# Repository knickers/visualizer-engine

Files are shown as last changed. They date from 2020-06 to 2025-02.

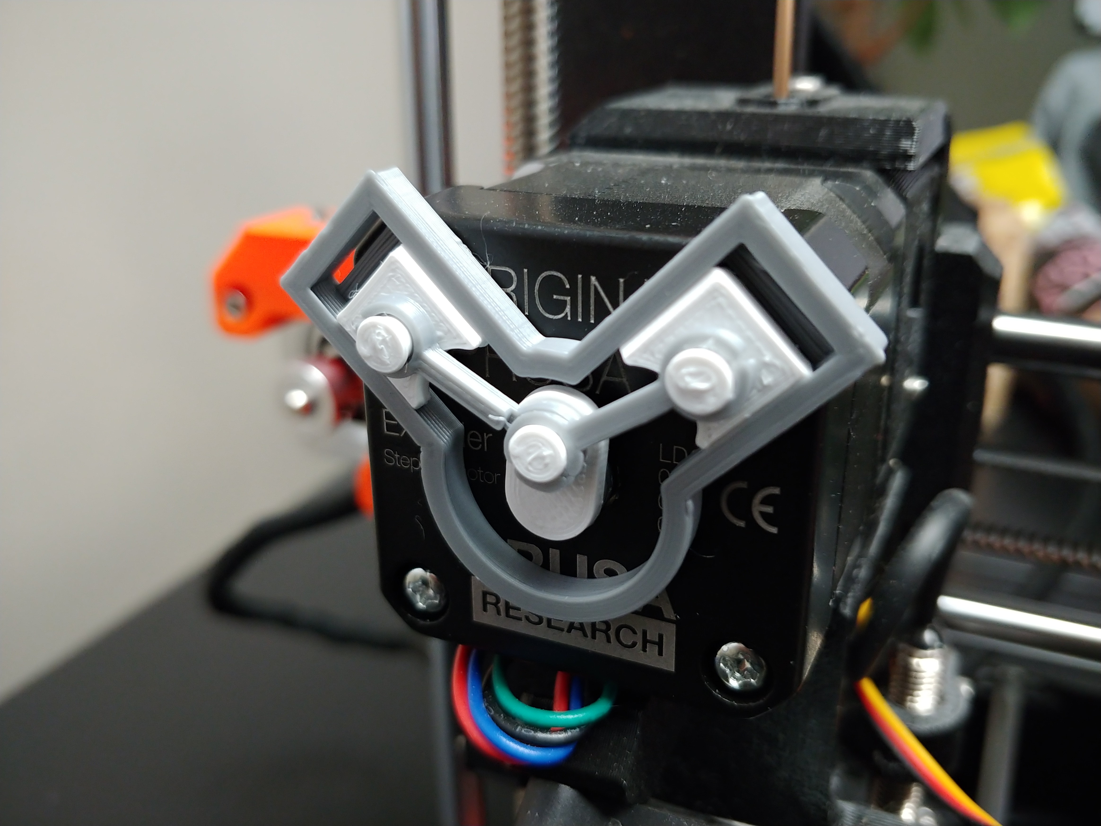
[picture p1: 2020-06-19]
img/20200121_165608.jpg

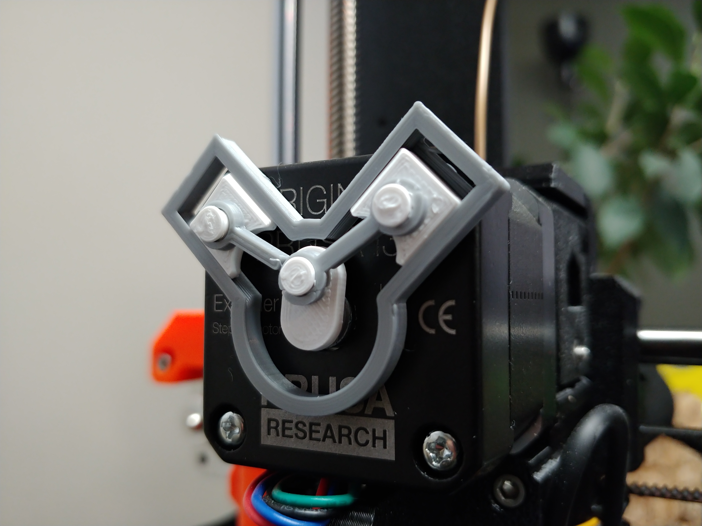
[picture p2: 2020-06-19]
img/20200121_165626.jpg

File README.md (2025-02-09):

# Reciprocating Kinetic Extruder Visualizer Engine

https://www.thingiverse.com/thing:4121683

Kinetic visualizer pistons for a more discernibly dynamic extruder, inspired by extruder visualizers from other designers. This is a reciprocating engine built to attach to your direct dive extruder motor. It can also attach to any motor which is ferrous, or has screw holes in the corners.

The crankshaft requires a neodymium magnet to hold itself to the stepper motor shaft, the default is **8 mm** diameter by **3 mm** tall.

The engine block is held on to the stepper motor with magnets. It can use the same size magnets as the crankshaft, 8mm X 3mm by default, or customize the size.

*Edit: Feb 8th 2025*
Switched to a magnet mounting system by default.

The legacy tab option is held in place by circular tabs that press fit into the screw holes of standard NEMA 17 stepper motors. The fit should be tight so the assembly holds itself in place securely. If the mounting tabs don't fit in your motor, edit the tab size in Thingiverse Customizer.

*Edit: June 26th 2020*
Added different cylinder configurations and a configurable propeller. These are not provided as pre-rendered STLs, make them in customizer. Choose these different cylinder numbers and angles:

* Single Cylinder
* V-Twin
* Flat Twin
* W Three
* Radial Four
* Clockwise or Counter Clockwise propeller
* 1-8 propeller blades

*Edit: May 8th 2020*
Added Thingiverse Customizer ability! Easily customize the engine to fit your motor right here in Thingiverse.

*Edit: Feb 16th 2020*
Added more versions with tighter tolerances. The original engine was rendered with 0.5 mm tolerances. Now choose between 0.5 mm, 0.4 mm, 0.3 mm, 0.2 mm and 0.1 mm tolerance. If you are unsure which one to choose, start with the 0.3 mm tolerance version.

Originally, this model was designed in OpenJSCAD. The `v-twin.jscad` file is now out of date and doesn't contain the new features of `engine.scad`. To customize the OpenJSCAD engine, load `v-twin.jscad` into the https://openjscad.org website and edit the parameters. Then choose an export format and click *Generate*, After that completes, click *Download*.

## Print Settings

3 perimeters for connecting rods and engine block so they are solid.

I tried to make my pistons as light as possible:

* 0 infill
* 1 bottom layer
* 2 top layers

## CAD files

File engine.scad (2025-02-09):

// Number, and angle, of cylinders
CONFIGURATION = 2; // [1:1 Cylinder, 2:2 Cylinders (V), 20:2 Cylinders (Flat), 3:3 Cylinders, 4:4 Cylinders]

// Distance between the stepper motor screws
MOTOR_SIZE = 31; // [20:0.1:50]

// Diameter inside the magnet mounting holes
MAGNET_DIAMETER = 8.05; // [4:0.01:10]

// Magnet thickness
MAGNET_HEIGHT = 3; // [1:0.01:5]

// Tolerance between moving parts
TOLERANCE = 0.3; // [0.1:0.05:0.5]

// Parts layout
VIEW = "Printing"; // [Printing, Combined, Exploded]

/* [Propeller] */

ENABLE_PROPELLER = 0; // [0:No, 1:Yes]
PROPELLER_BLADES = 2; // [1:1:8]
PROPELLER_DIRECTION = 1; // [1:Clockwise, -1:Counter Clockwise]

/* [Mounting Tabs] */

// How to fasten the visualizer engine to the stepper motor
MOUNTING_TYPE = "Magnet"; // ["Magnet", "Press-fit tab"]

// Diameter inside the motor screw holes
MOUNTING_TAB_SIZE = 6.15; // [4.5:0.01:7.5]

$fa = $preview ? 15 : 0.1;
$fs = $preview ? 1.25 : 0.6;     // Curve resolution
PIN     = 2 + 0;                 // Pin radius
WALL    = 2 + 0;                 // Wall thickness
SQRT2   = sqrt(2);               // Square root of 2
TOLHALF = TOLERANCE / 2;         // Half of the part tolerance
CRANK   = MOTOR_SIZE / 6;        // Crankshaft length
ROD     = MOTOR_SIZE / 1.9;      // Connecting rod length
PISTON  = MOTOR_SIZE / 3.1;      // Piston size
BLOCK   = 2+MAGNET_HEIGHT;       // Engine block thickness
SLEEVE  = CRANK+ROD+PISTON/2+WALL+0.5;               // Cylinder length from center
CYLINDERS = CONFIGURATION == 20 ? 2 : CONFIGURATION; // Number of cylinders
CYLINDER_ANGLE = CONFIGURATION == 20 ? 180 : 90;     // Angle between cylinders
MOUNT_TAB_R = MOUNTING_TAB_SIZE / 2;                 // Motor mount tab radius
PIN_HEIGHT = CYLINDERS == 1 ? 4 : CYLINDERS+2;



if (VIEW == "Printing") {
	draw_for_printing();
}
else if (VIEW == "Combined") {
	rotate([90, 0, 0])
		draw_combined();
}
else if (VIEW == "Exploded") {
	length = 3;
	rotate([90, 0, 0])
		translate([0, 0, -length*3])
			draw_combined(length);
}



/*************************
 *  Part layout modules  *
 *************************/

module draw_for_printing() {
	translate([0,0,(MOUNTING_TYPE == "Magnet" ? 0 : 4)])
		rotate((MOUNTING_TYPE == "Magnet" ? 0 : 180), [0,1,0])
			block();

	translate([0, CRANK/2, 0])
		crank();

	translate([0, MOTOR_SIZE+PISTON, 0])
		spacer();

	y = CYLINDERS == 4 ? MOTOR_SIZE : CRANK*3;
	x = PISTON * 2;
	offset = (CYLINDERS-1) * PISTON;

	for (i = [0:CYLINDERS-1]) {
		translate([-offset + x*i, -y-PISTON, 0]) {
			piston();
			translate([0, -PISTON-ROD, 0])
				rod();
		}
	}

	if (ENABLE_PROPELLER) {
		translate([MOTOR_SIZE*2.5, 0, 0])
			propeller();
	}
}

// https://en.wikipedia.org/wiki/Piston_motion_equations#Crankshaft_geometry
function piston_height(angle) =
	CRANK * cos(angle) + sqrt(ROD*ROD - CRANK*CRANK * sin(angle)*sin(angle));

module draw_combined(explode = 0) {
	a = $t * 360 + 90;           // angle of the crankshaft
	z = 4 + explode*6 + TOLHALF; // base z height of connecting rods
	nudge = 45;
	offset = (CYLINDERS-1) * (CYLINDER_ANGLE/2) - nudge;

	color("LightGrey")
	translate([0, 0, 4-BLOCK-explode])
		rotate([0, 0, offset])
			block();

	color("SlateGrey")
	translate([0, 0, 4-BLOCK+explode])
		rotate([0, 0, a])
			spacer();

	color("SlateGrey")
	translate([0, 0, 2+explode*2])
		rotate([0, 0, a])
			crank();

	for (i = [0:CYLINDERS-1]) {
		A = -i*CYLINDER_ANGLE + nudge; // angle of this piston sleeve iteration
		O = i % 2;                     // is this an odd iteration?

		color("SlateGrey")
		rotate([0, 0, -A])
			translate([0, piston_height(abs(180-A-a)), 2+explode*4])
				piston();

		color("LightGrey")
		translate([sin(a)*CRANK, -cos(a)*CRANK, i*(1+TOLHALF/2) + z])
			rotate([0, 0, asin(sin(a+A)*CRANK/ROD)-A]) {
				if (O || (CYLINDERS==3 && i==2)) {
					rotate([0, 180, 0])
						translate([0, 0, -1])
							rod();
				}
				else {
					rod();
				}
			}
	}

	if (ENABLE_PROPELLER) {
		translate([0, 0, 7+PIN_HEIGHT+TOLHALF+explode*7])
			rotate([180, 0, a-90])
				propeller();
	}
}



/**************************************************
 *  Modules for building each part of the engine  *
 **************************************************/

module pin() {
	// Pin body
	cylinder(r = PIN, h = PIN_HEIGHT);

	// Upper cone
	translate([0, 0, PIN_HEIGHT+0.5])
		cylinder(r1 = PIN + 0.5, r2 = PIN, h = 0.5);

	// Lower cone
	translate([0, 0, PIN_HEIGHT])
		cylinder(r1 = PIN, r2 = PIN + 0.5, h = 0.5);
}

module crank() {
	translate([0, -CRANK, 0])
		union() {
			pin();

			// Middle filler
			translate([-4, 0, 0])
				cube([8, CRANK, 2]);

			// Lower circle
			cylinder(r = 4, h = 2);

			// Upper circle
			translate([0, CRANK, 0])
				cylinder(r = 4, h = 2);

			if (ENABLE_PROPELLER) {
				p = PIN * 2 / SQRT2; // pin size
				translate([0, 0, PIN_HEIGHT+3])
					cube([p, p, 4], true);
			}
		}
}

module spacer() {
	cylinder(r = 4, h = BLOCK-2); // crankshaft spacer
}

// Connecting rod ring with a split for flexing over the pin head
module ring(height) {
	difference() {
		cylinder(r = PIN+TOLHALF+1, h = height);
		translate([0, 0, -1])
			cylinder(r = PIN+TOLHALF, h = height+2);
		translate([-TOLERANCE/2, 0, -1])
			cube([TOLERANCE, PIN+TOLERANCE+1, height+2]);
	}
}

module rod() {
	union() {
		difference() {
			union() {
				// Half height ring
				rotate([0, 0, 180])
					ring(CYLINDERS == 1 ? 2 : 1);

				// Middle bar
				translate([-1, PIN+TOLERANCE+1, 0])
					cube([2, ROD-PIN*2-TOLERANCE*1.5-1, 2]);

				// Lower bar filler
				translate([-1, PIN+TOLHALF, 0])
					cube([2, 2, CYLINDERS == 1 ? 2 : 1]);
			}
		}

		// Full height ring
		translate([0, ROD, 0])
			ring(2);
	}
}

module piston_body() {
	w = PISTON + 2;
	a = (w-TOLERANCE*2) / SQRT2;
	s = PISTON - TOLERANCE*2;

	translate([0, 0, 1])
		difference() {
			rotate([0, 45, 0])
				cube([a, PISTON, a], true); // main piston body

			translate([0, 0, PISTON/2+1])
				cube([s, PISTON+1, PISTON], true); // flatten top

			translate([0, 0, -PISTON/2-1])
				cube([s, PISTON+1, PISTON], true); // flatten bottom
		}
}

module piston() {
	union() {
		pin();

		difference() {
			piston_body();

			// curved cutout
			translate([0, -CRANK*2+1, -1])
				cylinder(r = CRANK+1, h = 4);
		}
	}
}

module mount_magnet() {
	ir = MAGNET_DIAMETER / 2;
	or = ir + 2;
	w = or * 2;
	difference() {
		cylinder(r = or, h = MAGNET_HEIGHT); // outside diameter
		translate([0, 0, -1])
			cylinder(r = ir, h = MAGNET_HEIGHT+2); // inside diameter
		translate([0, -or, MAGNET_HEIGHT-1])
			rotate(30, [1,0,0])
				translate([-w/2, 0, 0])
					cube([w, w, MAGNET_HEIGHT]); // Diagonal ramp
	}
	if (ir+2 <= PISTON/2) {
		for (i = [0:2])
			rotate(90*i, [0,0,1])
				translate([ir+1, -1, 0])
					cube([PISTON/2-ir, 2, 2]);
	}
}

module mount_tab() {
	d = MOUNT_TAB_R/2;
	w = PISTON + 2*WALL;

	translate([0, 0, -1])
		difference() {
			cylinder(r = MOUNT_TAB_R, h = 1); // outside diameter
			translate([0, 0, -1])
				cylinder(r = MOUNT_TAB_R-0.6, h = 3); // inside diameter
		}

	// upper crossmember
	translate([-w/2, MOUNT_TAB_R-2, 0])
		cube([w, 2, 1]);

	// lower crossmember
	translate([-w/2, -MOUNT_TAB_R, 0])
		cube([w, 2, 1]);

	// right support
	translate([MOUNT_TAB_R-1, -MOUNT_TAB_R/2, 0])
		cube([1, MOUNT_TAB_R, 0.5]);

	// left support
	translate([-MOUNT_TAB_R, -MOUNT_TAB_R/2, 0])
		cube([1, MOUNT_TAB_R, 0.5]);
}

module mounts() {
	s = MOTOR_SIZE / 2 * SQRT2;
	offset = (CYLINDERS-1) * CYLINDER_ANGLE/2;

	for (i = [0:CYLINDERS-1])
		rotate([0, 0, offset-i*CYLINDER_ANGLE])
			translate([0, s, 0]) {
				if (MOUNTING_TYPE == "Magnet") {
					mount_magnet();
				}
				else if (MOUNTING_TYPE == "Press-fit tab") {
					mount_tab();
				}
	}
}

module sleeve_outline() {
	w = PISTON + 2*WALL;
	W = w + 2;
	a = W / SQRT2;

	if (WALL < 2)
		translate([0, SLEEVE/2, BLOCK-1])
			intersection() {
				rotate([0, 45, 0])
					cube([a, SLEEVE, a], true); // piston track bulge

				cube([W, SLEEVE, 2], true); // flatten top
			}

	translate([-w/2, 0, 0])
		cube([w, SLEEVE, BLOCK]);
}

module sleeve_cutout() {
	a = (PISTON+2) / SQRT2;

	translate([-PISTON/2, -WALL, -1])
		cube([PISTON, SLEEVE, BLOCK+2]);

	translate([0, SLEEVE/2 - WALL, BLOCK-1])
		rotate([0, 45, 0])
			cube([a, SLEEVE, a], true); // piston track grooves
}

module sleeve() {
	difference() {
		sleeve_outline();
		sleeve_cutout();
	}
}

module block() {
	offset = (CYLINDERS-1) * CYLINDER_ANGLE/2;
	union() {
		difference() {
			union() {
				for (i = [0:CYLINDERS-1])
					rotate([0, 0, offset-i*CYLINDER_ANGLE])
						sleeve_outline();

				// block housing outer wall
				cylinder(r = CRANK+5+WALL, h = BLOCK);
			}

			for (i = [0:CYLINDERS-1])
				rotate([0, 0, offset-i*CYLINDER_ANGLE])
					sleeve_cutout();

			// block housing inner wall
			translate([0, 0, -1])
				cylinder(r = CRANK+5, h = BLOCK+2);
		}

		mounts();
	}
}

module propeller_blade() {
	l = MOTOR_SIZE + 4; // length of propeller blade
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

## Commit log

2020-06-19 Add the source files
    [v-twin.scad]
2020-06-19 Change noop variable preventer
    [v-twin.scad]
2020-06-19 Configurable wall thickness and cylinder count
    [v-twin.scad]
2020-06-19 Render correct number of (separated) pistons and rods
    [v-twin.scad]
2020-06-19 Change pin height for number of cylinders
    [v-twin.scad]
2020-06-19 Animate configurable number of cylinders
    [v-twin.scad]
2020-06-20 Move the combined module into a dev file
    [dev.scad, v-twin.scad]
2020-06-20 Uncomment the engine parts
    [v-twin.scad]
2020-06-20 Different piston cutouts for better preview rendering
    [v-twin.scad]
2020-06-20 Begin the propeller
    [dev.scad, v-twin.scad]
2020-06-26 Make sure the pistons won't hit each other
    [v-twin.scad]
2020-06-26 More consistent angle for combined animation
    [dev.scad]
2020-06-27 Update README for cylinder configurations
2020-06-27 Dynamic cylinder angle set by "Cylinder Configuration"
    [dev.scad, v-twin.scad]
2020-06-27 Rename from v-twin to engine
    [engine.scad]
2020-06-27 I dunno, white space
    [engine.scad]
2020-06-27 Remove quotation marks from configuration dropdown
    [engine.scad]
2020-07-10 Change the import filename
    [dev.scad]
2020-07-10 Configuration options
    [engine.scad]
2020-07-10 Propeller options
    [dev.scad, engine.scad]
2020-07-10 Propeller center hub tuning
    [engine.scad]
2020-07-10 Spread out the parts layout
    [engine.scad]
2020-07-10 Can't have commas in the config text
    [engine.scad]
2025-02-08 Comment wording
    [engine.scad]
2025-02-08 Better curve resolution calculation
    [engine.scad]
2025-02-08 Combine the dev file into the main file
    [engine.scad]
2025-02-09 Remove dev file
    [dev.scad]
2025-02-09 Add a magnet mounting option
    [engine.scad]
2025-02-09 Document magnet mounting system upgrade
2025-02-09 Reorganize the parameters
    [engine.scad]
